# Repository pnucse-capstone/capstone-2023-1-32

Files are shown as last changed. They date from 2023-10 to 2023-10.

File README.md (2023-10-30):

# **WI-SUN FAN 네트워크를 활용한 스마트 공유 주차장**

## 1. 프로젝트 소개
자동차는 대부분의 시간을 주차장에서 보내고, 운전자는 주행 시간의 30% 이상을 주차 공간을 찾는데 쓴다는 연구 결과가 있습니다. 하지만, 기존의 여러 공유 주차장 서비스들이 있었음에도 불구하고, '부정 주차 문제'로 인한 한계점이 명확했습니다. 

저희는 '부정 주차 문제'를 해결하고자 차단기가 부착된 공유 주차장 모듈을 제작하였습니다. 이를 활용해 IoT 기반의 공유 주차장 솔루션을 제시하고 주차 비효율 문제를 해결하는데 도움을 주고자 합니다.

## 2. 팀 소개
- 지도 교수님: 정상화 교수님
- 지도 조교님: 이희준 조교님

|이름|정우영|이창주|홍유준|
|-|-|-|-|
|github| [](https://github.com/wyj3569) | [](https://github.com/busbtvi) | [](https://github.com/Kick-snare) |
|학번|201824580|201824565|201824615|
|email|wyjung0731@gmail.com|busbtvi@gmail.com| hyjhyj0901@naver.com |
|역할|Wi-SUN 모듈 개발|서버 & 케이싱|안드로이드 앱 개발|

## 3. 구성도
- 전체적인 서비스의 구조도

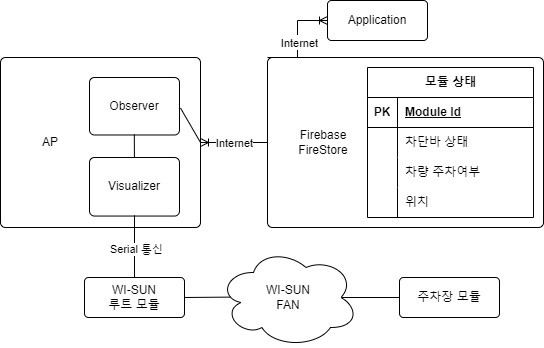
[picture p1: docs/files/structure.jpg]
서비스 전체 구조도
| 서비스 전체 구조도 |  |
| --- | :--- |
| **어플리케이션 서버** | 앱에서 활용할 데이터를 저장, Firebase의 FireStore를 활용 | 
| **AP(AccessPoint)** | 각 wi-sun 네트워크가 인터넷에 접속하기 위한 gateway |
| **WI-SUN Root Module** | AP에 연결되어 wi-sun fan 네트워크와 인터넷을 연결하는 역활 | 
| **주차장 모듈** | 차단기와 wi-sun 모듈을 포함하여, 주차장 바닥에 간단히 설치할 수 있는 모듈 |
| **애플리케이션** | 서버와 통신하며 사용자에게 UI 인터페이스를 제공 |

## 4. 소개 및 시연 영상

<!--| [<img width="500" src="https://github.com/pnucse-capstone/capstone-2023-1-32/assets/46425142/d3f03df4-c666-478d-8ad8-54723ae4332b"/>](https://youtu.be/7jfjwZkByfk?si=sUhvpEVTzl3uZno2) |
| --- |-->

정상주차장 팀 발표영상 (https://youtu.be/7jfjwZkByfk?si=sUhvpEVTzl3uZno2)

## 5. 사용법
> 이 프로젝트에 사용된 Wi-SUN 모듈의 경우, 기술적 권리로 인해 배포 및 공개가 금지되어 있습니다.
> 따라서, 해당 모듈과 관련된 source code 및 사용법은 이 repository 및 README에 포함하지 않았습니다.

### 5.1 주차장 모듈
> 주차장 모듈은 주차공간 소유자가 자신의 주차장에 간편하게 설치하여, 부정주차 차량을 차단할 수 있는것을 목표로 개발되었습니다.

#### 완성된 모듈

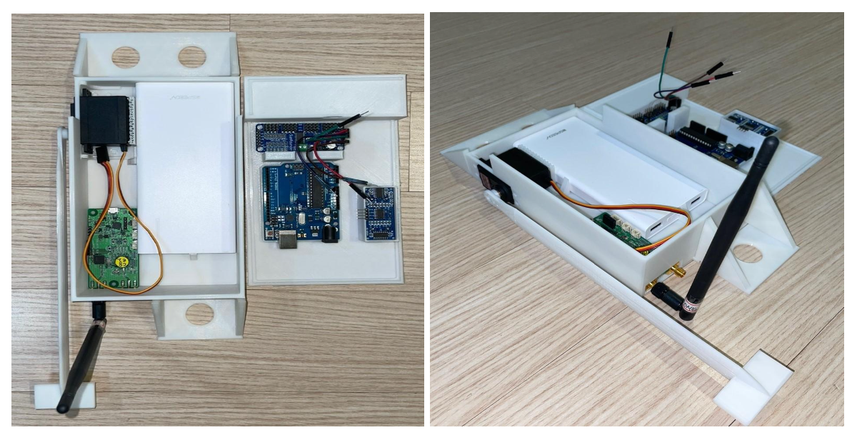
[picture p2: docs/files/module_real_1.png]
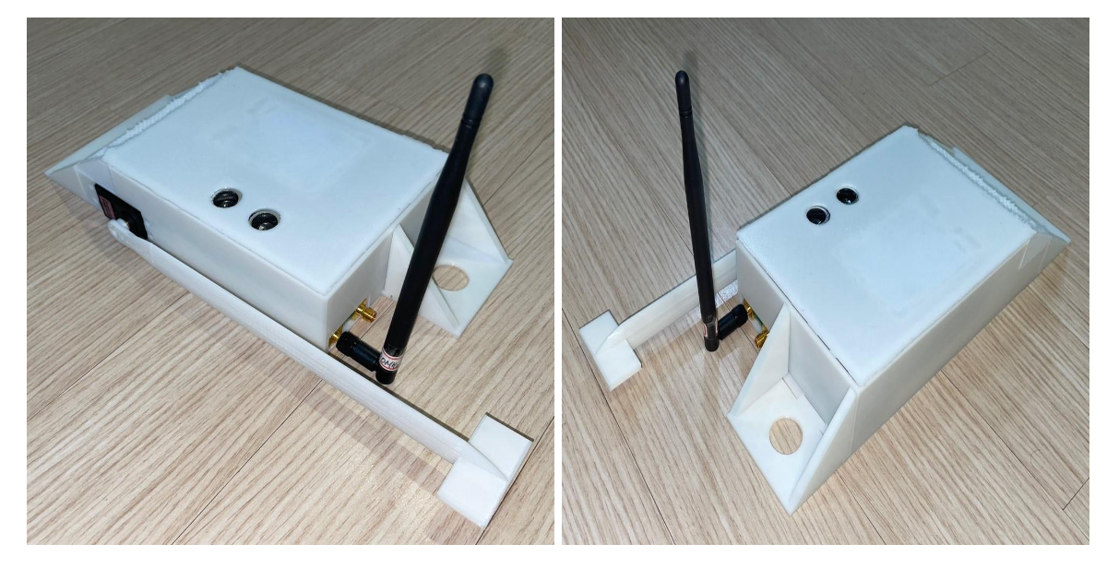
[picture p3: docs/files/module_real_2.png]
|  |  |
| --- | --- |

- 위의 주차장 모듈은 주차면에 차량이 주차되어 있는지 여부를 실시간으로 파악합니다.
- 주차장 모듈에 부정 주차를 방지할 수 있는 차단바 기능을 구현했습니다.
- 차단바의 움직임은 사용자가 애플리케이션을 통해서 조작합니다.
- 우리 공유 주차장 시스템은 Wi-SUN FAN 네트워크를 이용하여 통신합니다. 

Wi-SUN FAN 네트워크를 이용한 통신을 간략히 요약하면 다음과 같습니다.

- Wi-SUN FAN 네트워크의 모든 패킷은 루트 노드를 경유한다.
- 루트 노드를 관찰하는 옵저버를 둔다.
- 옵저버는 Wi-SUN 모듈과 서버 사이의 패킷을 중간에서 연결하는 역할을 수행한다.

### 5.2 Observer
> observer는 AP에서 실행되어, firebase와 wi-sun 모듈간의 양방향 통신을 책임지는 python 코드입니다.

<details>
<summary>**How to run**</summary>
    
#### How to run

1. python 3.* version
2. firebase 프로젝트에서 firebaseCredential.json을 다운받아 observer.py와 동일한 경로에 배치한다. 
    - 프로젝트 설정 -> 서비스 계정 -> 새 비공개키 생성
3. wireshark를 활용해 wi-sun모듈이 사용하고 있는 인터페이스 및 포트를 확인
    - port: observer.py 16 line 수정
    ```python
    port = ????
    ```
    - interface: observer.py 88 line 'iface' 값 수정
    ```python
    sniff(iface="????", prn = handlePacket, count = 0)
    ```
4. run observer.py

</details>

<details>
<summary>**코드 설명**</summary>

#### 코드 설명
- 서버를 firebase로 사용하고 있기 때문에, firebase 까지 업데이트를 하면 어플리케이션에서 자동으로 반영

1. 모듈 -> 어플리케이션
    1. 주차장 모듈에 설치된 wi-sun 모듈이 root 로 데이터를 전송
    2. root 모듈은 AP에 있는 visualizer에게 전달
    3. 2번의 과정을 python의 scapy를 활용해 캡처
        ```python
        from scapy.all import *
        sniff(iface="wisun", prn = handlePacket, count = 0)
        ```
    4. 패킷을 분석해 필요한 데이터 추출
        ```python
        def handlePacket(rowPacket)
        ```
    5. firestore에 업데이트
        ```python
        def updateDocument(mac, isOcupied): nodeRef.document(mac).update({"isOcupied": isOcupied})
        ```
2. 어플리케이션 -> 모듈
    1. observer에서 firestore에 대한 EventListener 등록
        ```python
        # 변화를 감지할 collection(일종의 table)
        nodeRef = firestore.client().collection("module")
        
        # 현재 observer와 관련된 문서만 탐지
        col_query = nodeRef.where(filter=FieldFilter("observerId", "==", observerId))
        query_watch = col_query.on_snapshot(documnetEventListener)
        ```
    2. 문서의 flag 필드값을 확인
        ```python
        for change in changes:
            if change.type.name == "MODIFIED":
                msg = 0 if change.document.get("isBlocked") else 1
        ```
    3. 데이터(제어신호)를 socket을 활용해, interface로 전달
        ```python
        def sendToNode(dst, msg):
        print("sendToNode")
        sendSocket.connect((dst, port))
        sendSocket.send(msg.to_bytes(1, 'big'))
        ```
</details>

### 5.3 Android

스크린샷 2023-10-27 오후 11 45 56

사용자의 모바일 어플리케이션과 주차장 모듈 간의 통신을 위해 Firebase의 FireStore 서비스를 사용한다. 모듈과 모바일 앱과 같은 다른 클라이언트와 통신하기 위해서 많은 부분이 계층화되어 있기 때문에 모바일 애플리케이션은 주차장 관련 정보를 오직 firestore를 인터페이스로 주고 받는다. 

#### 회원가입 및 로그인

| 로그인 | SNS연동 | 회원가입 |
| --- | --- | --- |
|  |  |  |

주차장을 대여하거나, 제공하는 사용자 모두 회원가입을 통해 로그인이 필요하다. 간편한 로그인을 지원하기 위해 카카오의 SNS 로그인을 지원하도록 연동하였다. 따라서 사용자는 별다른 입력 없이 바로 로그인 할 수 있다.

#### 지도 기반 주차장 탐색

|  |  |  |  |
| --- | --- | --- | --- |

기본적으로 앱을 실행하였을 때 사용자는 지도를 통해 주차장의 여러 정보를 얻을 수 있다. 자신의 위치를 비롯한 주차장들의 위치와 이름이 지도상의 마커로 표시 된다. 

하단 네비게이션바 위 쪽의 “-” 모양의 핸들을 드래그하여 올리게 되면 주차장들의 간략한 정보가 담긴 카드 리스트가 노출된다. 이는 지도 상에 노출되는 주차장들의 더욱 자세한 정보를 알 수 있으며, 카드 우측 상단의 별 모양을 통해 즐겨찾기를 등록 또는 해제 가능하다. 이는 서버에 즉시 반영되며, 등록된 주차장은 “즐겨찾기” 탭에서 모아 보기 가능하다.

주차장 마커를 클릭하거나, 아래 리스트에서 카드를 클릭하게 되면 왼쪽 화면과 같이 지도의 시점이 고정되며 현재 위치로부터 주차장 위치의 경로를 애니메이션으로 보여준다. 동시에 지도 상에 떠있는 주차장 카드가 노출되며, 해당 카드를 클릭하면 주차장의 상세 정보와 함께 결제를 할 수 있는 화면으로 이동하게 된다.

### 사용 시간에 따른 필터링

| 주차장 사용 시간 | 날짜 선택 | 시간 선택 |
| --- | --- | --- |
|  |  |  |

사용자는 자신이 주차를 원하는 시작 시간과 종료 시간을 설정하여 이 조건에 맞게 사용할 수 있는 주차장을 탐색하고, 해당하는 가격을 결제하여 사용할 수 있다. 편리한 사용을 위해 아래 “+” 또는 “-”가 붙은 버튼을 클릭하여 간편하게 시간을 조정할 수 있다. 하단 아래의 큰 버튼을 눌러 적용한다.

#### 주차장 모듈 등록

| 주차장 관리 | 권한 획득 | QR코드 스캔 | 주차장 정보 입력 |
| --- | --- | --- | --- |
|  |  |  |  |

주차장을 제공자로서 사용하기 위해서는 모듈을 동작시켜 네트워크상에 연결되고 나서, 주차장에 대한 세부 정보와 제공자가 누구인지 등 등록하는 과정이 필요하다. 추후 모듈을 제공할 때 케이스에 QR스티커 등을 부착하여 모바일 애플리케이션에서 카메라로 인식하여 간단하게 구현할 수 있도록한다. 
 인식이 된 모듈은 주차장의 이름, 위치, 가격등을 설정하여 서버에 저장되고, 최종적으로 사용자에게 노출되게 된다. 

### 5.4 Casing(H/W)
> 이번 과제에서 사용된 모든 모델링 파일은 /docs/files/*.stl 파일에 있습니다.

케이싱은 주차장 모듈에 필요한 센서와 보드들이 모두 안전하게 보관 및 동작할 수 있도록 모델링을 진행했습니다. 

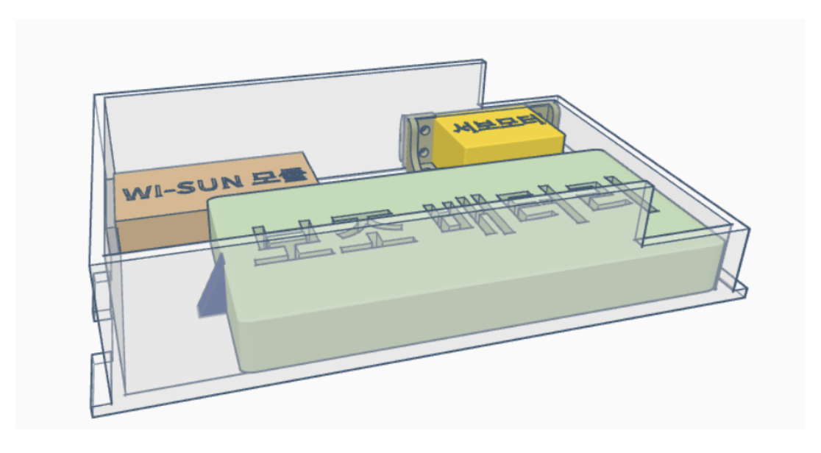
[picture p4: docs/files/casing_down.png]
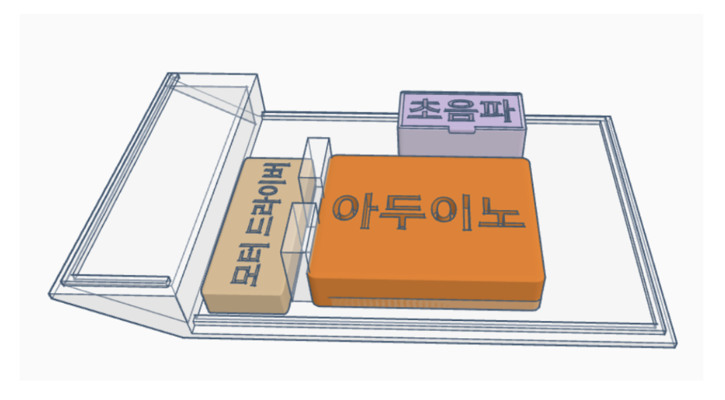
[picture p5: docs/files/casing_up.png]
|  |  | 
| --- | --- |

- 차단바를 움직이는데 필요한 서보모터의 구동축은 바깥에서 보이도록 하였고, WI-SUN 모듈의 안테나도 외부에서 장착할 수 있도록 제작했습니다.
- 초음파 센서는 위쪽의 차량의 주차여부를 판단해야 되기 때문에 케이싱의 뚜껑부분에 장착될 수 있도록 제작했습니다.

#### 전체 케이싱

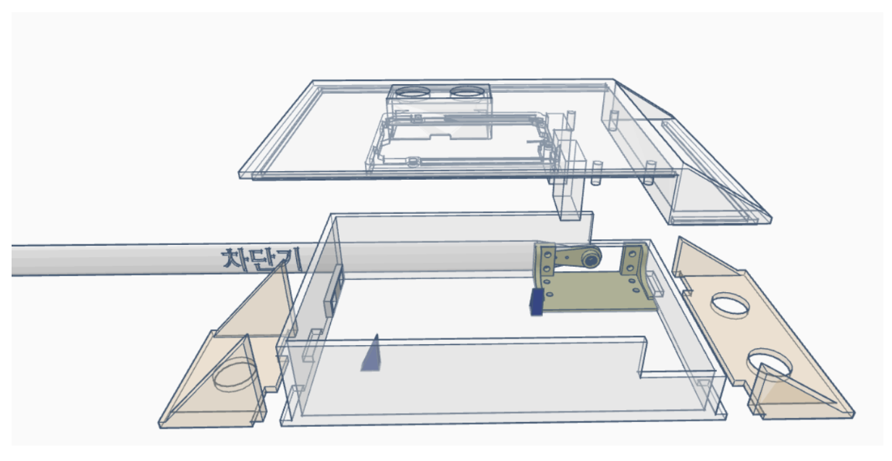
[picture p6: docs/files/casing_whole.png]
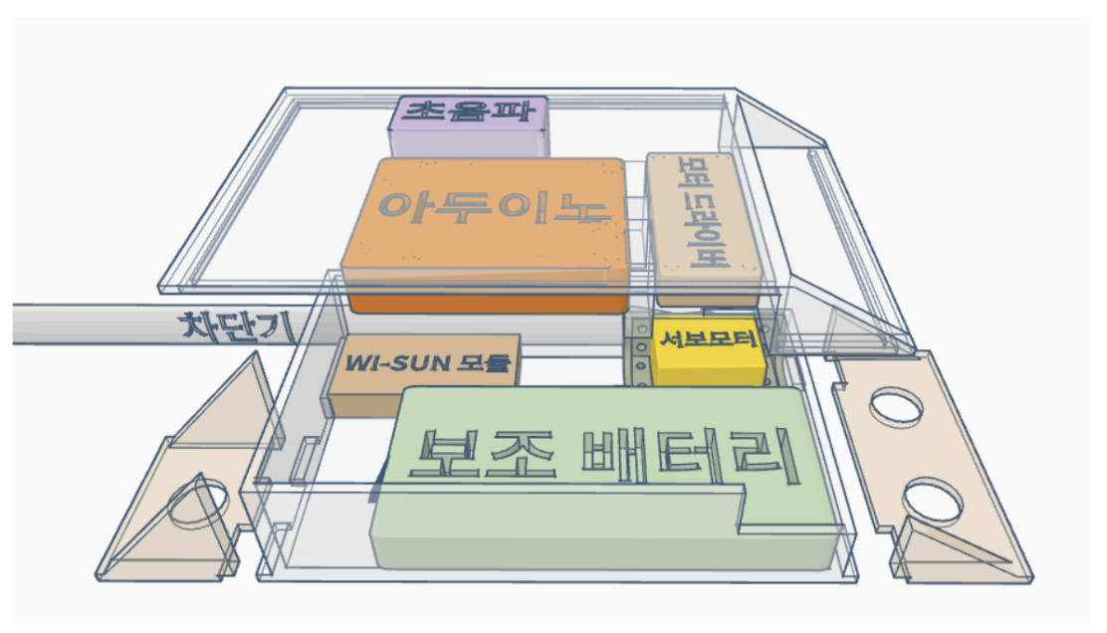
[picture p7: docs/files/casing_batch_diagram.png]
|  |  | 
| --- | --- |

- 모듈이 주차장 바닥에 안정적으로 고정될 수 있도록 케이싱의 좌우에 지지부를 따로 빼내어 바닥에 볼트를 박을 수 있도록 설계
- 지지부가 케이스에 정확히 연결 될 수 있도록 케이싱 및 지지부에 가이드 추가

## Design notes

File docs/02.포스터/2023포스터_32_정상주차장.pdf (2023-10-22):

# Wi-SUN FAN 네트워크를 활용한

# 33 스마트 공유 주차장

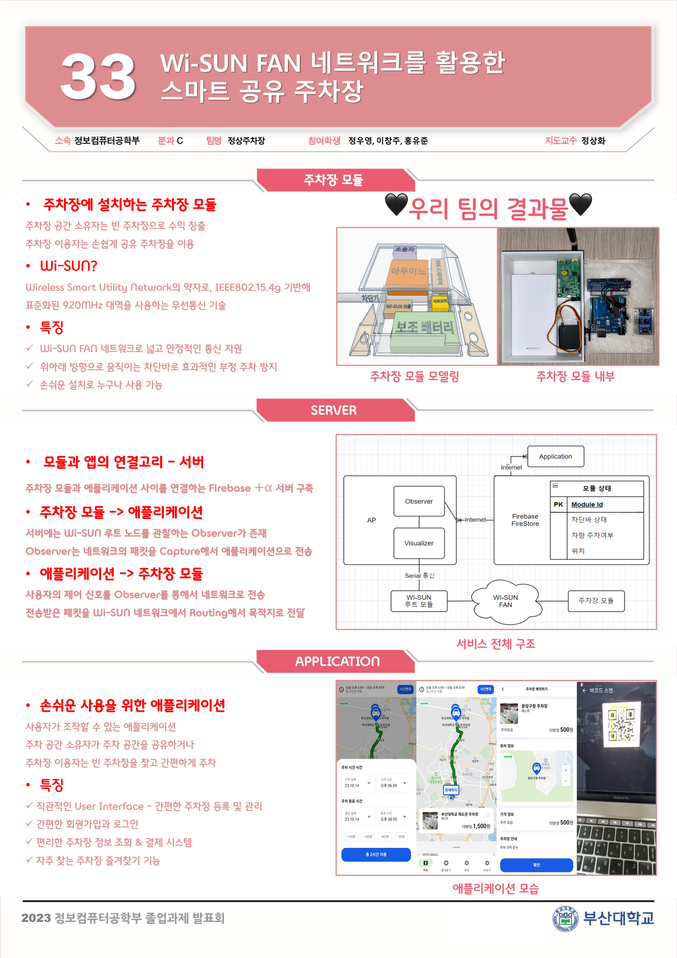
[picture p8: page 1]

정상주차장 | 정우영, 이창주, 홍유준 | 정상화

### 주차장 모듈

### SERVER

### APPLICATION

2023

주차장 모듈 모델링 | 주차장 모듈 내부

## - 주차장에 설치하는 주차장 모듈

주차장 공간 소유자는 빈 주차장으로 수익 창출
주차장 이용자는 손쉽게 공유 주차장을 이용

## - Wi-SUN?

Wireless Smart Utility Network의 약자로, IEEE802.15.4g 기반해 표준화된 920MHz 대역을 사용하는 무선통신 기술
- 특징

ü Wi-SUN FAN 네트워크로 넓고 안정적인 통신 지원
ü 위아래 방향으로 움직이는 차단바로 효과적인 부정 주차 방지 ü 손쉬운 설치로 누구나 사용 가능

# 🖤우리 팀의 결과물🖤

## - 모듈과 앱의 연결고리 서버

주차장 모듈과 애플리케이션 사이를 연결하는 Firebase +α 서버 구축

## - 주차장 모듈 -> 애플리케이션

서버에는 Wi-SUN 루트 노드를 관찰하는 Observer가 존재 Observer는 네트워크의 패킷을 Capture해서 애플리케이션으로 전송

## - 애플리케이션 -> 주차장 모듈

사용자의 제어 신호를 Observer를 통해서 네트워크로 전송
전송받은 패킷을 Wi-SUN 네트워크에서 Routing해서 목적지로 전달

## - 손쉬운 사용을 위한 애플리케이션

사용자가 조작할 수 있는 애플리케이션
주차 공간 소유자가 주차 공간을 공유하거나
주차장 이용자는 빈 주차장을 찾고 간편하게 주차
- 특징

ü 직관적인 User Interface 간편한 주차장 등록 및 관리 ü 간편한 회원가입과 로그인
ü 편리한 주차장 정보 조회 & 결제 시스템
ü 자주 찾는 주차장 즐겨찾기 기능

### 서비스 전체 구조

### 애플리케이션 모습

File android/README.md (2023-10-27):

# NormalizeParkingLot-android
Normalize the Parking Lot (NPL) android repository

### How To Run
```
1. add local.properties
2. sync gradle
3. build & run
```
request @kick-snare `local.properties` that contains api key

### app architecture

```mermaid
flowchart TD
    A[app] --> B(data)
    A[app] --> G(presentation)
    G --> B
    G --> C{ui}
    C --> D[map]
    C --> E[favorite]
    C --> H[provider]
    C --> F[setting]
    B --> repository
    repository --> interface
    repository --> impl
    B --> di
    B --> remote
    remote --> service
    remote --> dto
    B --> local
    local --> dao
    local --> entity
```
with MVVM

### tech stacks
- Jetpack Compose
- Kotlin Coroutine
- Dagger Hilt
- FireStore
- Retrofit
- Coil
- etc...

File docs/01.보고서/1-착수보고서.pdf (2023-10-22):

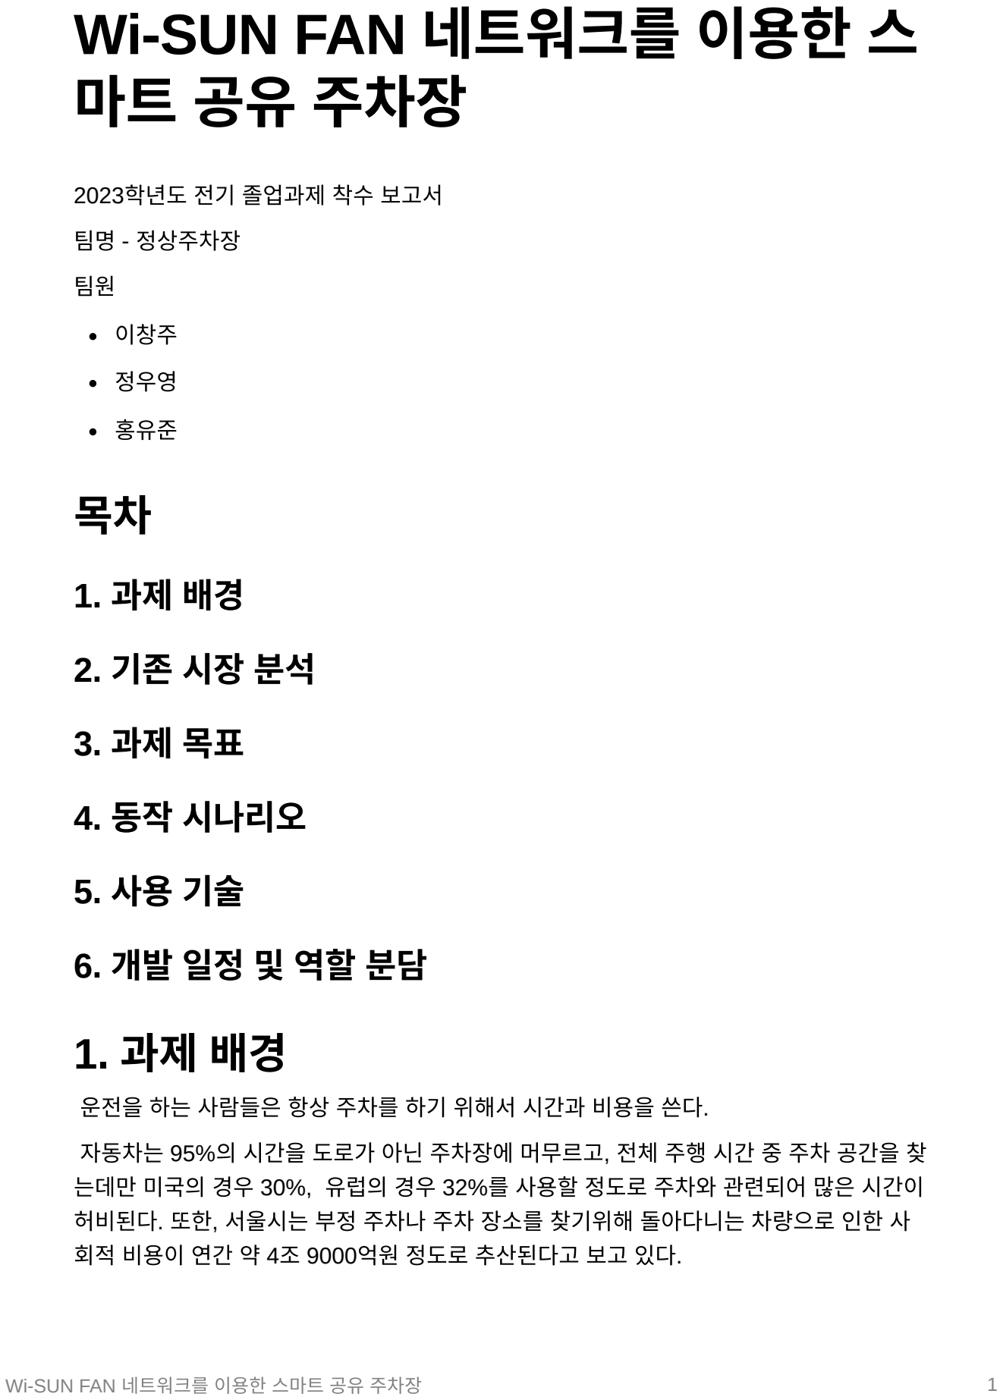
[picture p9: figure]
Wi-SUN FAN 네트워크를 이용한 스마트 공유 주차장; Wi-SUN FAN 네트워크를 이용한 스 마트 공유 주차장; 2023학년도 전기 졸업과제 착수 보고서; 팀명 - 정상주차장; 이창주; 정우영; 홍유준; 4. 동작 시나리오; 운전을 하는 사람들은 항상 주차를 하기 위해서 시간과 비용을 쓴다.; 회적 비용이 연간 약 4조 9000억원 정도로 추산된다고 보고 있다.

자동차는 95%의 시간을 도로가 아닌 주차장에 머무르고, 전체 주행 시간 중 주차 공간을 찾 는데만 미국의 경우 30%, 유럽의 경우 32%를 사용할 정도로 주차와 관련되어 많은 시간이 허비된다. 또한, 서울시는 부정 주차나 주차 장소를 찾기위해 돌아다니는 차량으로 인한 사

그러나 이러한 문제가 ‘주차 공간 부족’ 때문만은 아니다. 실제 통계 자료에 따르면, 서울시 의 경우 평균 주차공간 확보율이 2022년 기준 141%, 종로구의 경우는 무려 185.5%로 등록 된 차량보다 주차 공간이 거의 2배에 가까운 상황이다.

충분한 주차공간이 있음에도 불구하고, 주차와 관련된 비효율이 높은 이유는 주차공간에 대 한 수요와 공급이 불균형하기 때문이라는 연구 결과가 존재한다. 주차 공간의 전체 공급은 충분하지만, 주차 공간의 수요는 특정 시간대에만 몰려있기 때문에 비효율이 발생한다는 것 이다. 이러한 문제를 해결하기 위한 방안으로 ‘공유 주차장’ 개념이 고안되었고, 현재 시중에 이러한 서비스가 존재하고 있다.

하지만 부정 주차 문제를 쉽게 해결할 수 없기 때문에 여전히 여러 문제가 존재한다. 이러한 문제를 해결하기 위해서 우리 팀은 여유 부지를 공유주차장으로 쉽게 운영하면서도 부정 주 차 문제를 해결할 수 있는 `IoT(Internet of Things) 기반 공유 주차장 서비스’를 제안하고 자 한다.

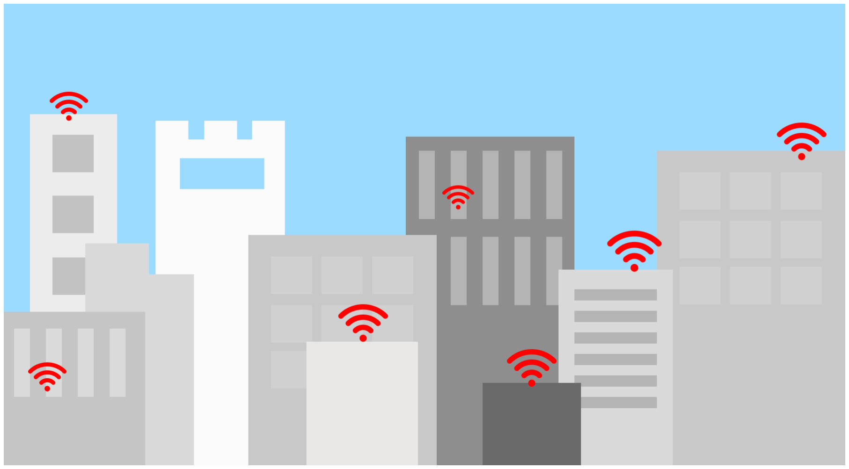
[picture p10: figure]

해당 서비스를 개발하기 위해서 주차면에 간단하게 설치할 수 있는 Iot 모듈과, 관련 서비스 를 쉽게 제공하고자 소프트웨어를 개발하고자 한다. 모듈간의 통신을 위해서 IPv6 주소체계 를 기반으로 넓은 범위를 효율적으로 커버할 수 있는 Wi-SUN FAN (Wireless Smart Utility Network-Field Area Network)을 사용한다. 추가적으로 네트워크의 성능 향상과 관련된 연 구를 수행해서 더욱 빠르고 효율적인 네트워크 시스템을 구축해보고자 한다. 사용자들에게 해당 서비스를 제공하기 위한 모바일 애플리케이션을 개발한다.

# 2. 기존 시장 분석

## 2.1 모두의 주차장

‘모두의 주차장’은 대표적인 주차장 공유 사업, 주차장 제휴 사업, 주차장 정보 사업 등을 모 바일 애플리케이션 형태로 사용자들에게 제공하는 플랫폼이다.

특히, 주차 공유 서비스는 주차공간 소유자와 운전자가 주차장을 공유할 수 있도록 연결해 주는 서비스로 거주자 우선 주차면과 사유지 주차공간을 공유하도록 하는 서비스이다. 주차 공간 소유자는 해당 서비스를 통해 비워두는 시간을 활용해서 수익을 얻고, 운전자는 공유 주차장을 활용해 저렴한 가격으로 단속 걱정 없이 편리하게 주차할 수 있다.

모두의 주차장은 현재도 지속적으로 서비스를 제공하고 있다. 하지만, 공유 주차장의 부정 주차 방지 수단으로 경고 문구 부착, 부정주차 단속 및 차주에게 직접 말하기와 같은 방법에 의존하고 있다. 그래서 실제 사용자들이 막상 공유 주차 공간에 갔을 때 부정주차 차량이 이 미 자리하고 있는 경우가 있다는 점이 단점으로 지적되고 있다. 따라서, 부정주차를 효과적 으로 예방할 수 있는 방안을 마련할 필요가 있어 보인다.

2.2 파킹플렉스 (https://medium.com/@TaerimPark_CEO/%ED%8C%8C%ED%82%B9%ED%94%8C%EB%A0%89%EC%8A%A4-%ED%9A%8C%EA%B3%A0%EB%A1%9D-6a1653b7a5be)

‘파킹플렉스’는 2017년 서비스를 종료한 IoT 기반의 주차공간 공유 서비스이다. 파킹플렉스 는 주인의 동의를 받은 주차 공간에 차량을 감지할 수 있는 IoT 센서를 부착해서 주차 공간의 상태 정보를 애플리케이션을 통해 운전자에게 실시간으로 전달하는 서비스를 개발했었다. 그러면 운전자는 주차 공간을 찾아가서 애플리케이션을 통해 주차비를 지불하고 주차 공간 을 사용할 수 있었다.

하지만, 주차 공간 주인에게 돌아가는 수익이 낮은 점, 불법 주차 예방 효과 미미, 불편한 애 플리케이션 사용자 경험, 당시 사람들에게 익숙하지 않은 IT 기반 서비스 등과 같은 문제로 서비스를 종료하게 되었다.

특히, 파킹플렉스는 부정주차 방지 솔루션으로 (1)공유 설정된 주차 공간에서 주차비를 결 제하지 않고 10분 이상 지난 경우, (2)공유 미설정된 주차 공간에서 10분 이상 차량이 주차 된 경우 해당 구청이나 공간 소유자에게 알림을 보내는 방법을 사용했다. 이러한 소극적인 대응 방법 때문에 부정 주차 예방 효과가 미미하여 공간 소유자로 하여금 서비스를 사용하게 할 동기를 주지 못했던 것으로 판단된다.

출처-모두의주차장 (https://www.moduparking.com/)

이러한 사례를 미루어 보아, 더욱 적극적으로 부정주차를 예방할 수 있는 방법을 찾을 필요 가 있어 보인다. 또한, 더욱 사용자 친화적인 경험을 제공한다면 당시보다 더욱 많은 사람들 이 IT 기반 서비스에 익숙해진 지금 성공적인 서비스가 될 수 있을 것이라 생각한다.

# 3. 과제 목표

## 3.1 주차장 모듈 개발

주차 공간 소유자가 자신의 주차 공간을 운전자에게 공유하고자 할 때, 관련 기능을 제공할 수 있는 주차장 모듈을 개발한다. 아래에 제시된 기능들을 모두 하나의 모듈로 제작해서 간 편하게 설치할 수 있는 형태를 제안한다.

주차장 모듈에 필요한 기능으로 다음이 있다.

(1) 주차 가능 여부 파악 기능

주차면에 설치된 모듈에서 초음파 센서를 활용하면 주차 여부를 판단할 수 있다. 초음파 센 서로 파악한 주차 가능 여부를 서버에 보내주면, 운전자는 모바일 애플리케이션을 통해서 근 처에 주차 가능한 공유 주차장의 존재를 확인할 수 있다.

(2) 부정 주차 방지를 위한 차단 기능

주차장 모듈에는 부정 주차 방지를 위한 차단 기능이 존재한다. 일반적으로 주차장은 아래 의 그림과 같이 2가지 유형의 배열로 구성되어 있다. 보통 위의 유형은 공영 주차장과 같은 곳에서 볼 수 있고, 아래의 유형은 주택가와 같은 곳에서 볼 수 있는 주차장 배열이다.

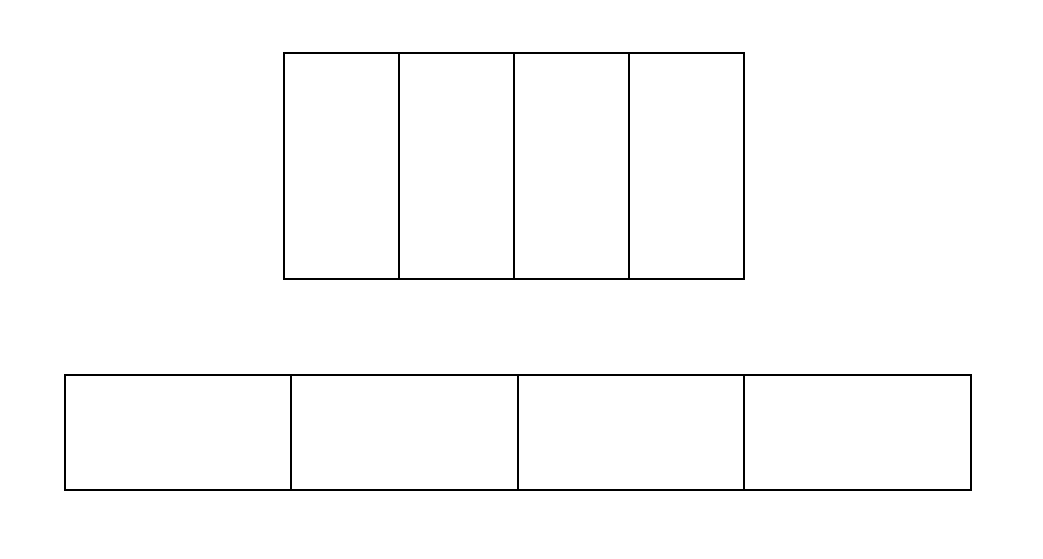
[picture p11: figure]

만약, 아래와 같이 흔히 볼 수 있는 차단기를 설치한다면 2가지 길이의 차단기를 제작해야 하고, 또한 주차면마다 이와 같은 차단기를 설치한다면 진입 공간을 방해하고 비용도 많이 드는 문제점이 있다.

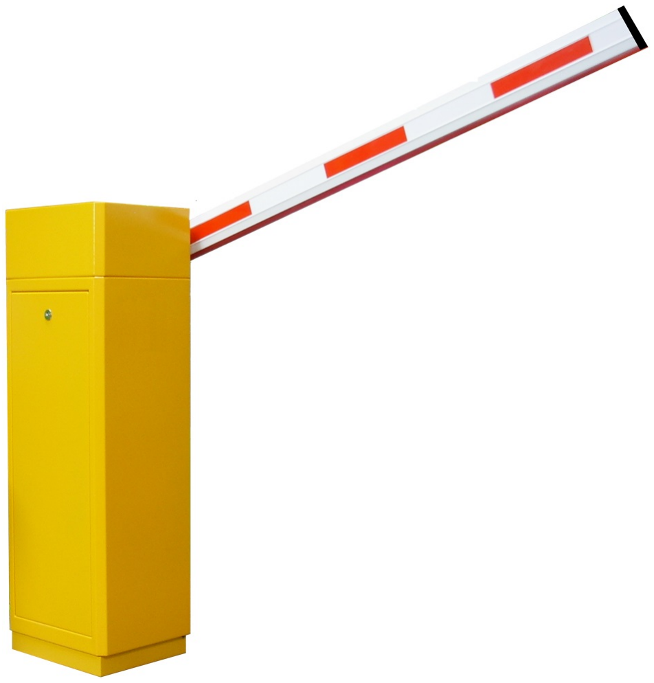
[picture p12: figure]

이러한 문제점을 해결하기 위해서 발상을 전환하여 아래와 같이 주차면 바닥에서 서고 접을 수 있는 형태의 차단기를 제작하고자 한다. 이와 같은 차단기를 주차면의 중앙에 하나씩 설 치한다면 동일한 길이의 차단기를 하나만 제작해도 되고, 부정 주차 차량의 진입을 제한할 수 있으며, 주차 가능 여부를 확실하게 판단할 수 있을 것이다.

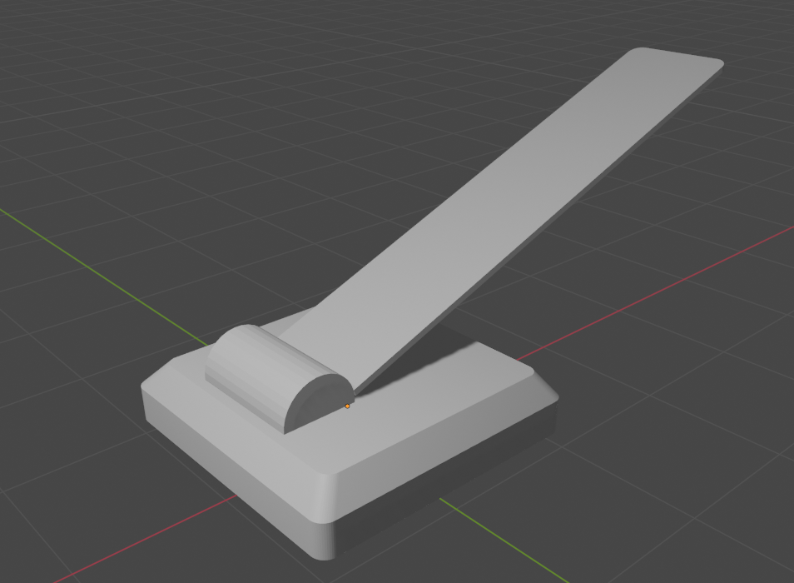
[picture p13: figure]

(3) Wi-SUN FAN을 통한 통신 기능

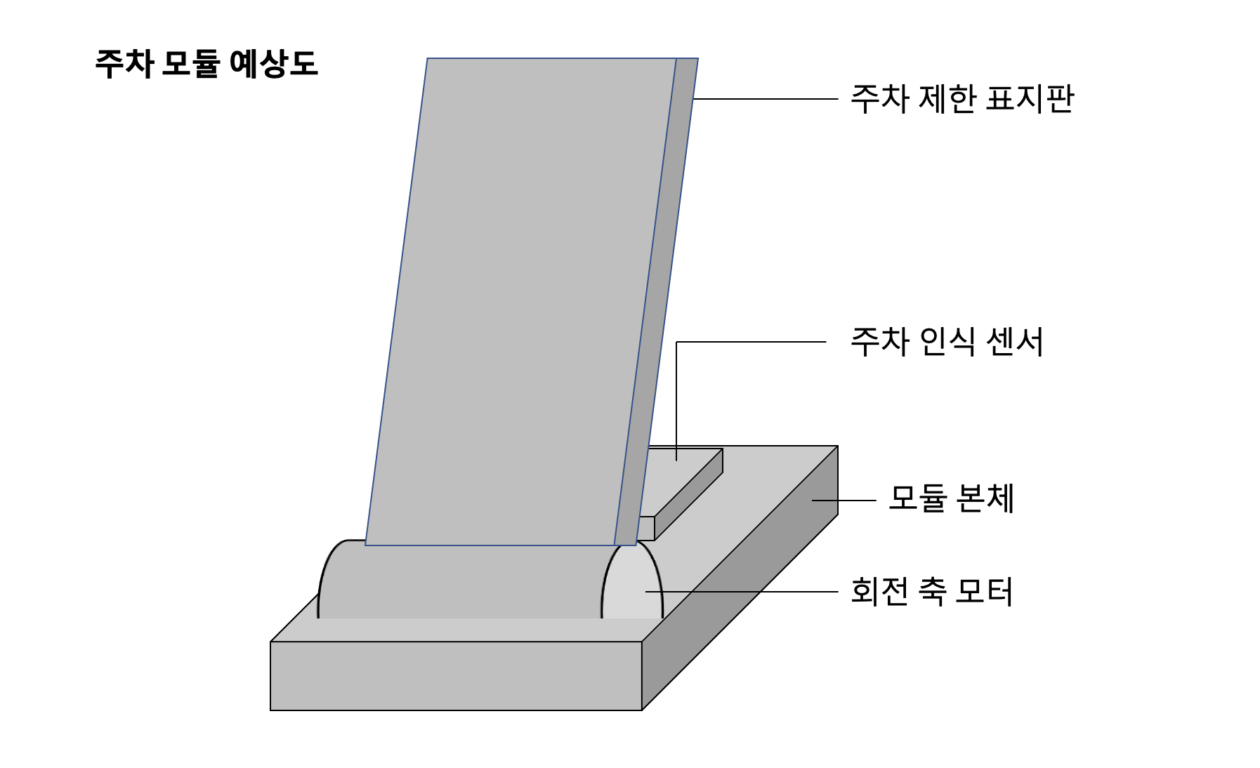
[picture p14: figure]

주차 모듈에 Wi-SUN FAN 모듈을 장착하여 상호간의 통신을 수행한다.

## 3.2 애플리케이션 개발

주차 공간 소유자와 운전자가 공유 주차 서비스를 사용할 수 있도록 애플리케이션을 개발한 다.

(1) 회원가입 및 로그인 기능
(2) 지도 서비스를 통한 주차 가능 공간 안내 기능
(3) 주차 공간 예약 기능
(4) 자주 사용하는 주차공간 예약기능

출처-건일하이텍 (http://kiht.net/product1/)

(5) 디지털 결제 기능과 결제 기록 제공 기능

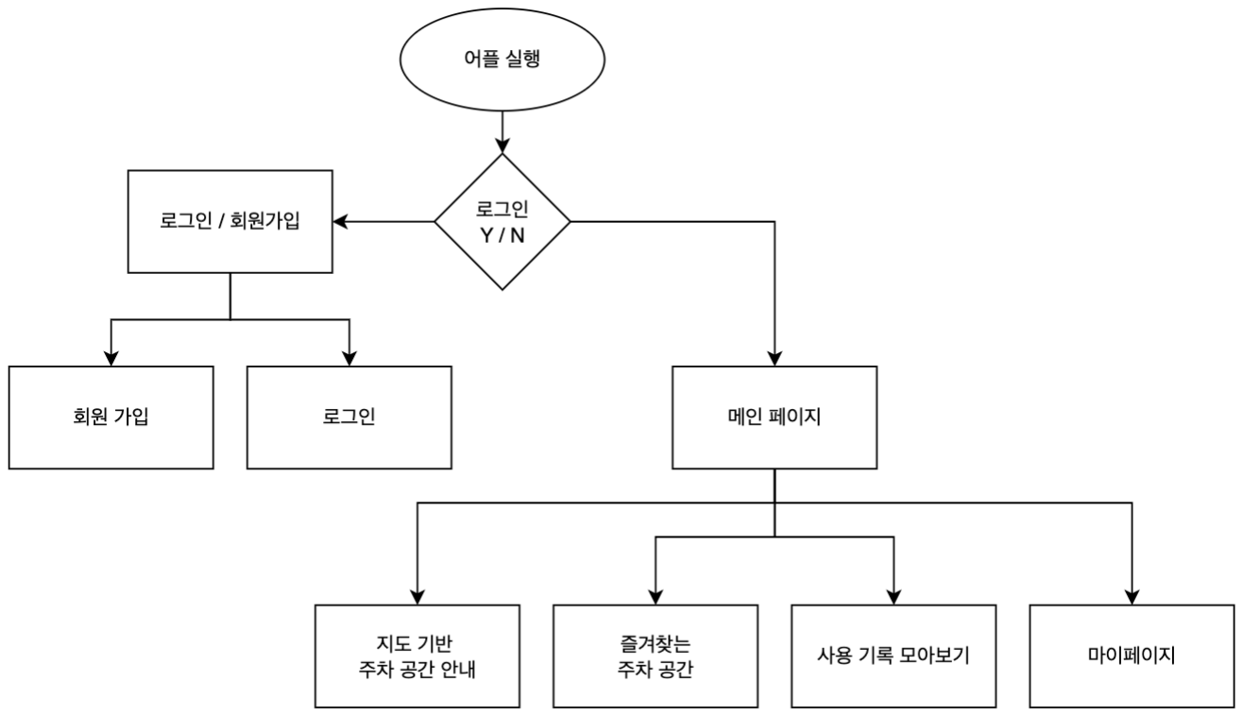
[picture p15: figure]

## 3.3 서버 개발

주차장 모듈과 모바일 클라이언트 애플리케이션 사이에서 정보를 관리하는 서버를 개발한 다.

(1) 주차장 모듈로부터 주차 가능 여부 송신 기능
(2) 사용자 애플리케이션에게 주차 가능 여부 수신 기능
(3) 사용자 관리 기능
(4) Wi-SUN FAN 기반의 통신 기능
(5) REST API를 통한 인터페이스 제공 기능

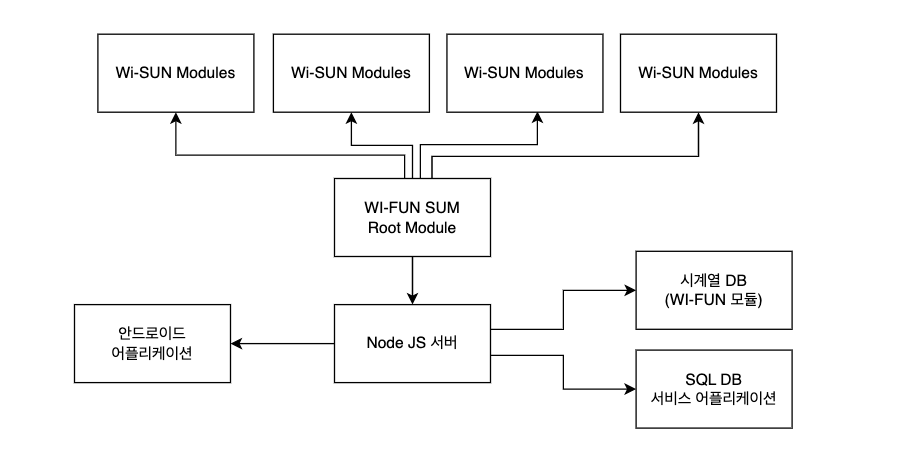
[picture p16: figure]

## 3.4 네트워크 성능 개선

Wi-SUN FAN 네트워크 자체의 성능 향상과 관련된 연구를 수행한다.

예상 가능한 연구 주제로는 다음이 있다.

(1) RPL(IPv6 Routing Protocol for Low-power Lossy Networks) 경로 설정 최적화 연구
(2) 공유 주차 서비스에 최적화된 데이터 포맷, 송수신 주기 탐색 연구

# 4. 동작 시나리오

### 4.1 주차 공간 소유자의 경우

주차 공간을 소유한 사람이 주차공간이 놀고 있는 시간에, 잠시 대여를 해 약간의 수익을 창 출 하고 싶을 때, 어플리케이션을 다운받아 공간 소유자로 등록을 하고, 모듈 구매한다. 그리 고 모듈을 원하는 위치의 주차 공간 바닥면에 설치하고 해당 위치를 어플리케이션으로 등록 한다.

등록한 주차공간에 사용될 때 마다 알림을 받아보는 등 실시간 상태와 수익률등을 확인할 수 있으며 원하지 않는 경우 주차지 공유를 중지할 수 있다.

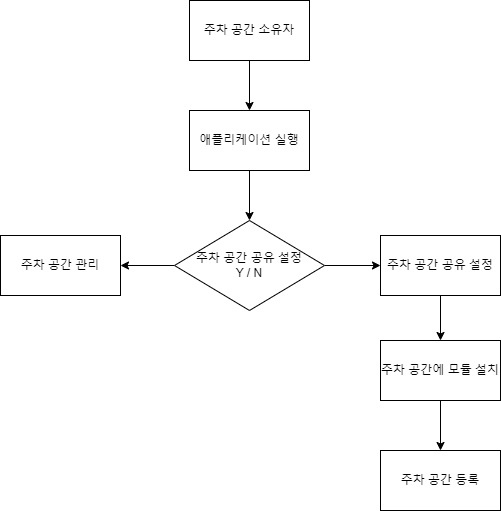
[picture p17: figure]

### 4.2 운전자의 경우

일반 사용자는 주차 공간이 필요한 경우, 어플리케이션 상의 지도에서 원하는 지역에 유휴 주차 공간을 찾아볼 수 있다. 적절한 주차지를 찾는다면 원하는 시간만큼 해당 공간에 대한 예약이 가능하다.

사용자가 예약한 주차장에 도착하면 어플리케이션 상에서 사용자의 위치를 인식하여 서버와 연결된 차량 차단장치가 해제되어 주차가 가능해진다. 사용자가 주차를 끝내고 장소를 이탈 하고 나면, 모듈에 탑대된 초음파 센서로 인식하여 자동으로 차량 차단장치를 가동해 주차공 간의 부정 이용을 제한한다.

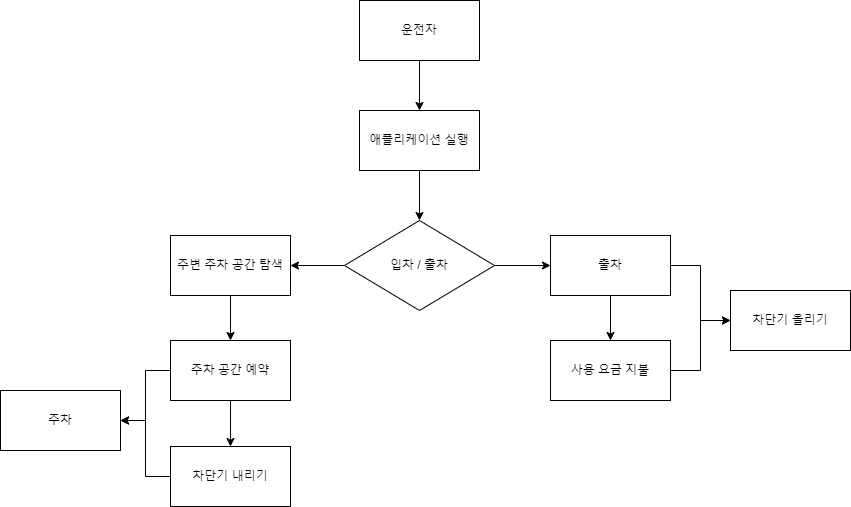
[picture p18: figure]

# 5. 사용 기술

## 5.1 WI-SUN FAN

Wi-SUN은 Wireless Smart Utility Network의 약자로, 920MHz 주파수를 사용하는 무선 통신 규격이다. Wi-SUN은 2.4GHz 및 5GHz대 주파수를 사용하는 Wi-Fi에 비해 통신 속도 는 느리지만, 통신 거리가 길고 장해물에도 강하기 때문에 통신이 용이하며, 저소비전력이라 는 장점이 있는 사물인터넷 전용 네트워크이다.

Wi-SUN은 최하층 프로토콜 베이스로 IEEE 802.15.4g를 사용하고, 그 상위층은 어플리케 이션에 따라 Profile이 정해져 있다. 이 중 FAN 응용은 사회 기반 시설, 고도 도로 교통 시스 템 등 스마트 시티, 스마트 그리드를 구축하는 다양한 어플리케이션을 상정한 Field Area Network용 프로파일이다.

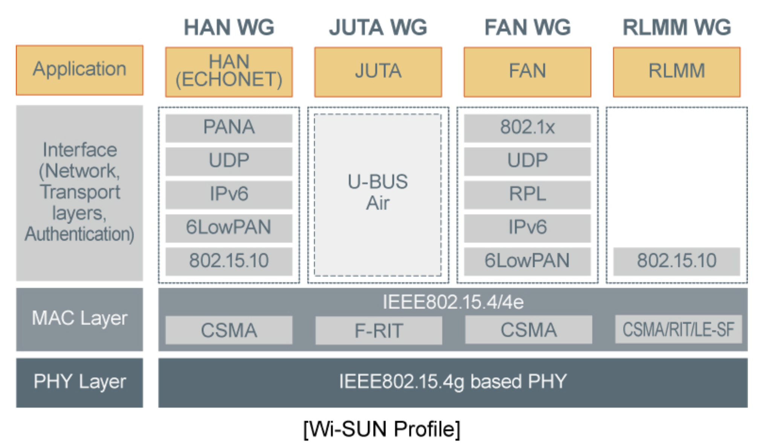
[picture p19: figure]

## 5.2 Android

리눅스 커널을 기반으로 구글에서 제작하고 있는 모바일용 운영체제이다. 커널은 C, C++로 작성되있고, UI 및 소프트웨어는 Java(또는 Kotlin)로 ART(Android RunTime)에서 동작한 다.

## 5.3 Node.js

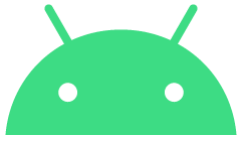
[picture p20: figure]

오픈소스 자바스크립트 엔진인 ‘V8’에 비동기 이벤트 처리 라이브러리인 ‘libuv’를 결합한 플랫폼으로, 자바스크립트 코드를 브라우저 외부에서 실행할 수 있게 해준다.

본 과제에서는 Node.js를 WI-SUN 모듈과 모바일 애플리케이션을 연결하는 서버로써 활용 할 예정이다.

출처-ROHM (https://www.rohm.co.kr/electronics-basics/wireless/wireless_what4)

출처-안드로이드 (https://www.android.com/intl/ko_kr/)

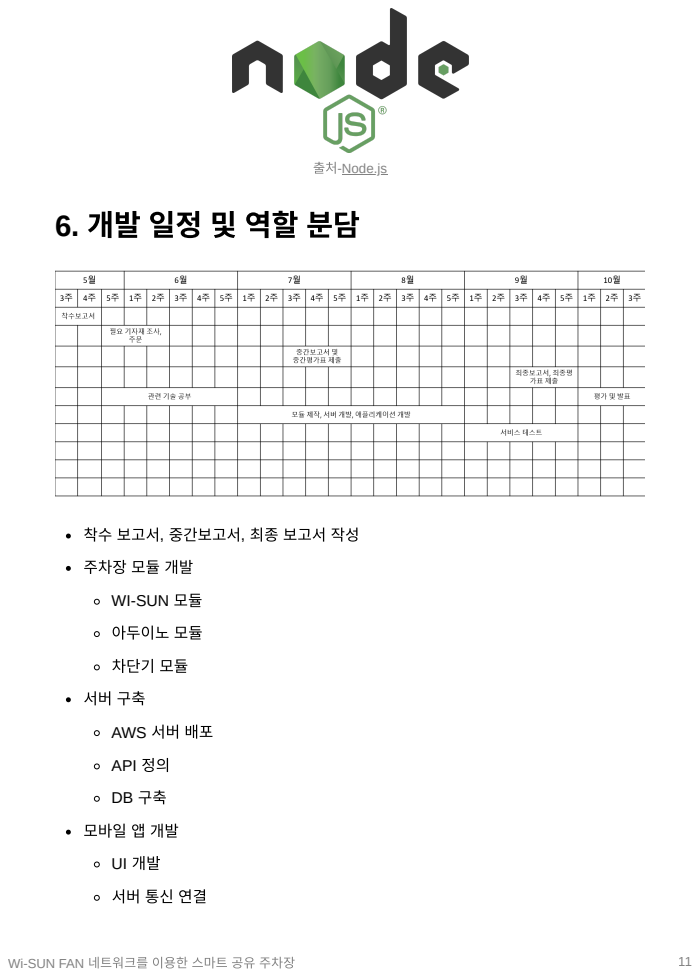
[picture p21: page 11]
아두이노 모듈; 차단기 모듈; 모바일 앱 개발

출처-Node.js (https://nodejs.org/ko)

착수 보고서, 중간보고서, 최종 보고서 작성

주차장 모듈 개발
WI-SUN 모듈

AWS 서버 배포
API 정의

로컬 DB 구축

| 역할
공통 | WI-SUN FAN 네트워크 망 연결 및 구축
정우영 | 모듈 제작, 네트워크 프로그래밍
이창주 | WI-SUN 루트 모듈과 서버 통신 연결, NodeJS서버 구축
홍유준 | 서비스 모바일 안드로이드 어플리케이션 구현

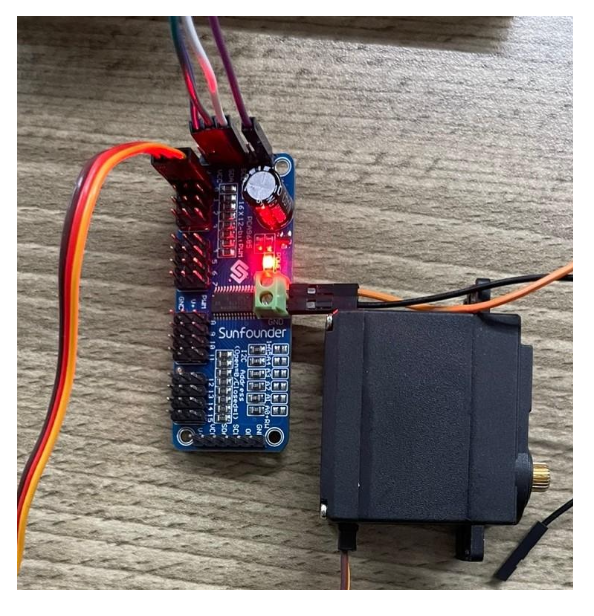
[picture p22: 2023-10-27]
docs/files/motor driver and servo motor.png

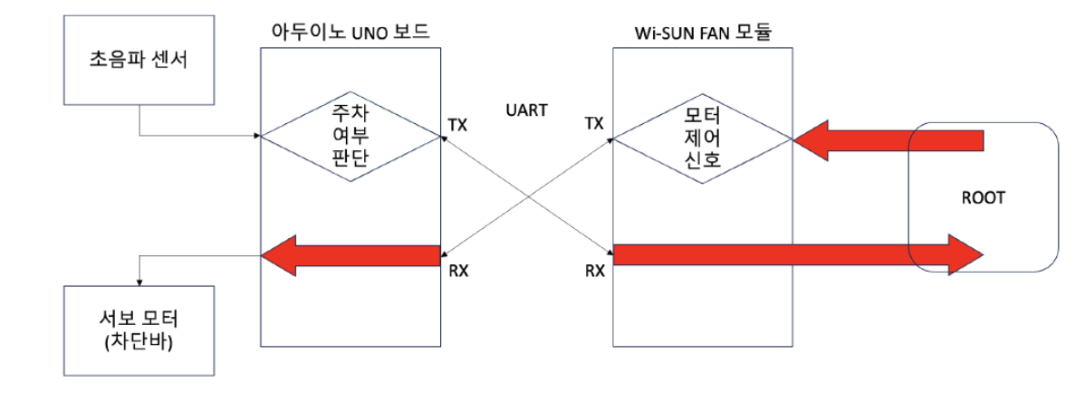
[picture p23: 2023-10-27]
docs/files/module structure.png

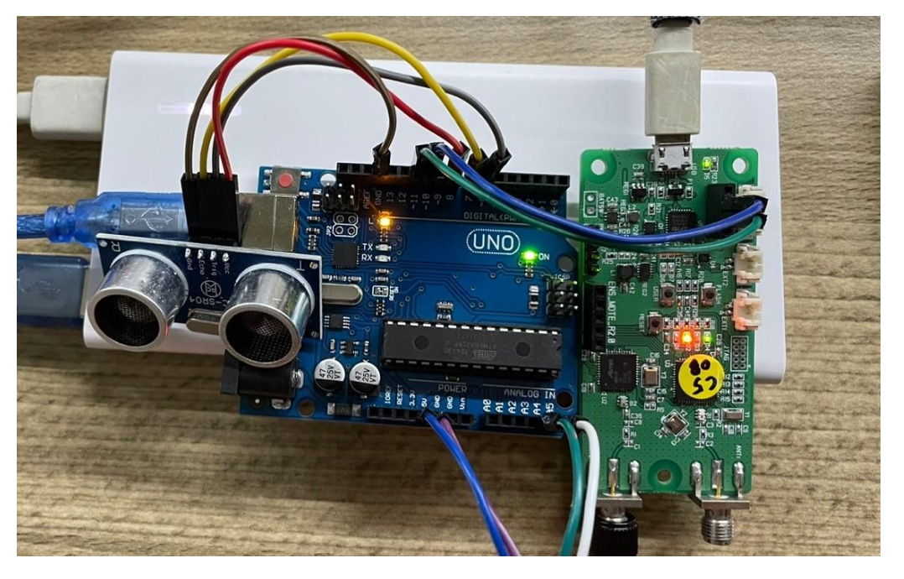
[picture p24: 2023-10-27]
docs/files/arduino and wisun module.png

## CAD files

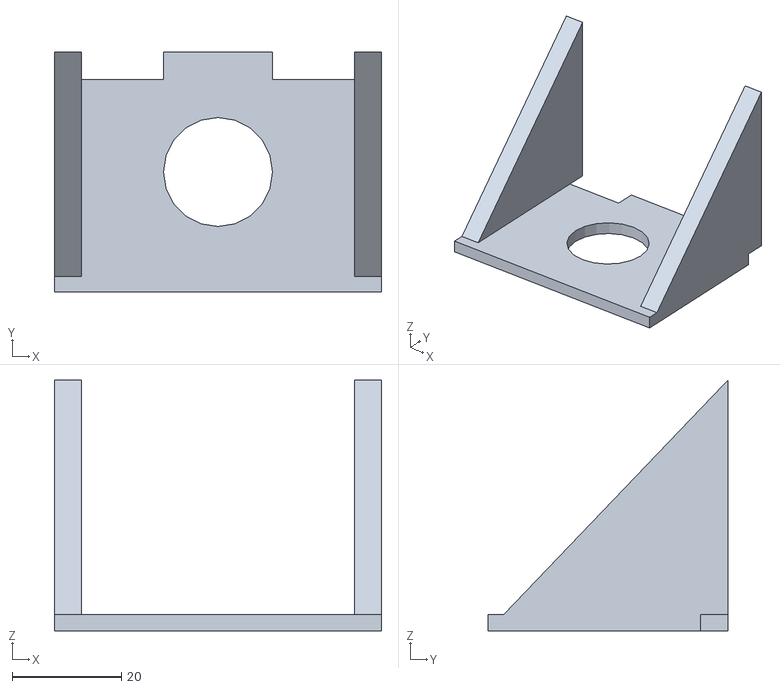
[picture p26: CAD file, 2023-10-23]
docs/files/wing_2.stl
60.0 x 44.0 x 46.0

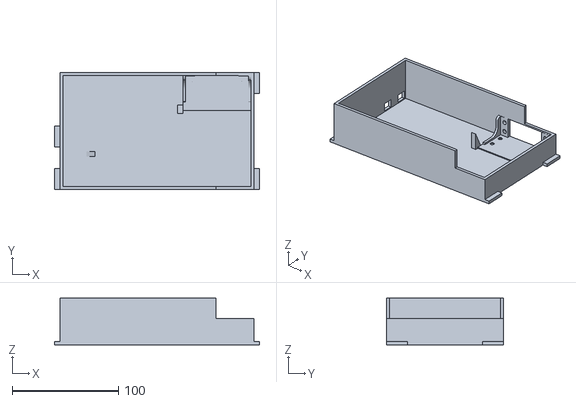
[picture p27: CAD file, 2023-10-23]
docs/files/bottom case v5.stl
193.0 x 110.3 x 44.0

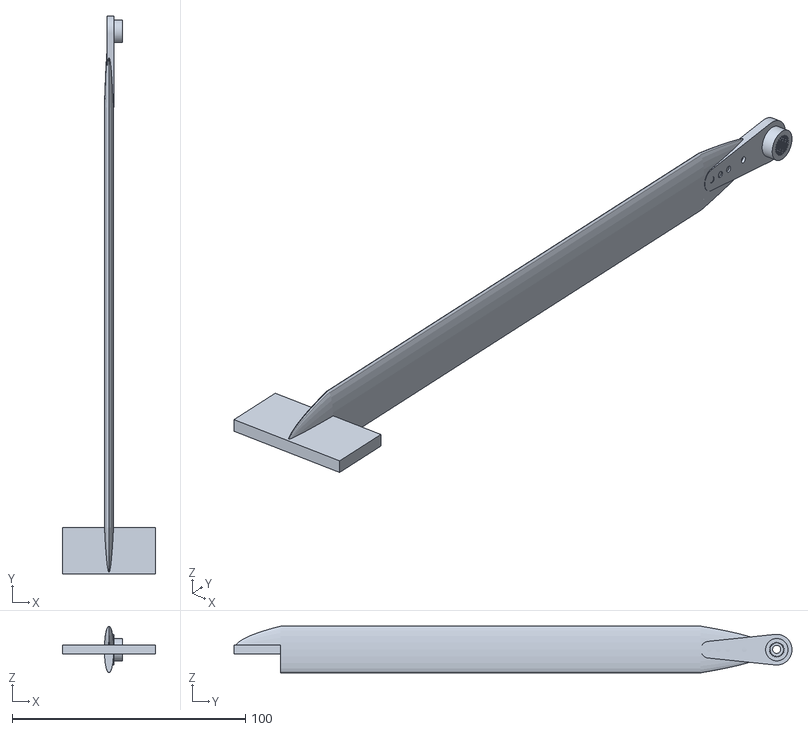
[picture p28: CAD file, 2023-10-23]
docs/files/arm.stl
40.0 x 239.1 x 20.0

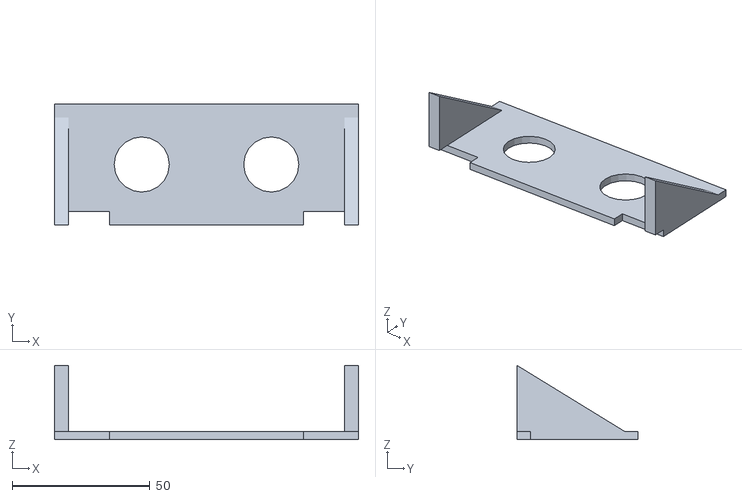
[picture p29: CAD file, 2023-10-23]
docs/files/wing_1.stl
110.3 x 44.0 x 27.0

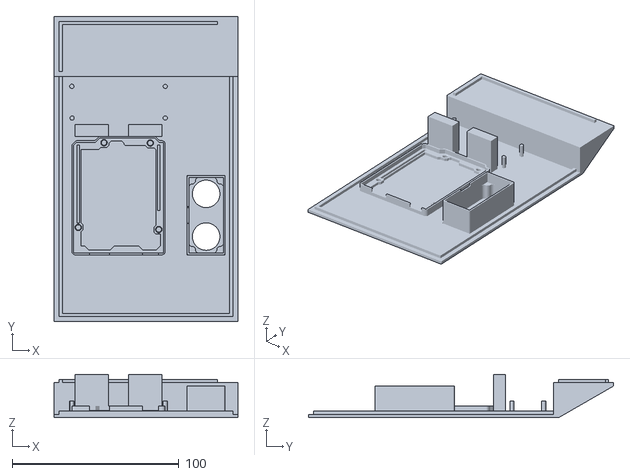
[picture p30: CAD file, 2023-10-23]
docs/files/top case v5.stl
110.3 x 183.0 x 26.0

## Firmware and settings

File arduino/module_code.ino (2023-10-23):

#include <Servo.h>
#include <SoftwareSerial.h>
#include <NewPing.h>
#include <Adafruit_PWMServoDriver.h>

// wi-sun용 시리얼 통신 포트
#define RX 10 // blue
#define TX 11 // green

#define MOTOR_DRIVER_VCC    8

// 초음파 센서
#define TRIGGER_PIN  6 // gray
#define ECHO_PIN     7 // yellow
#define MAX_DISTANCE 500

// 서보모터
Servo servo;
// 모터 드라이버-서보모터
Adafruit_PWMServoDriver pwm = Adafruit_PWMServoDriver();

// 기본 시리얼 통신 포트 데이터
char serial_data = '0';

// wi-sun용 시리얼 통신 포트 지정
SoftwareSerial mySerial(RX, TX);
// wi-sun용 시리얼 통신 포트 데이터
char myserial_rx = '0'; 

// 초음파 센서
NewPing sonar(TRIGGER_PIN, ECHO_PIN, MAX_DISTANCE);
uint8_t myserial_tx = 0;





void setup() {
  Serial.begin(9600);
  mySerial.begin(9600);

  servo.attach(9);

  pinMode(MOTOR_DRIVER_VCC, OUTPUT);

  pwm.begin();
  pwm.setPWMFreq(51);
}


void loop() {
  digitalWrite(MOTOR_DRIVER_VCC, HIGH);


  // 키보드 입력 (서보 작동 테스트용)
  if (Serial.available()) {
    // serial_data = Serial.read();
    // Serial.println("From keyboard: "); Serial.print(serial_data);

    // if (serial_data == '0') { // 올림
    //   Serial.println("motor up");
    //   servo.write(90);
    //   delay(100);
    // } else if (serial_data == '1') { // 내림
    //   Serial.println("motor down");
    //   servo.write(0);
    //   delay(100);
    // }

    // 시리얼 모니터로 값 입력
    int a = Serial.parseInt();
    // 받은 값의 범위 0~180을 펄스길이 150~600으로 매핑
    // ra의 최대 최소를 150, 600을 넘지 않게
    int ra = constrain(map(a, 0, 180, 150, 600), 150, 600);

    // pca9685 모듈의 0번 포트에 연결된 서보를 ra만큼 회전
    pwm.setPWM(0, 0, ra);

    // 시리얼 모니터에 출력
    Serial.print('('); Serial.print(a); Serial.print(','); Serial.print(ra); Serial.println(')');
    delay(10);
  }

  // Wi-SUN -> 아두이노 (서보 제어)
  if (mySerial.available()) {
    myserial_rx = mySerial.read(); // UART1으로 서보 제어 값 읽기
    Serial.println("Servo control get: "); Serial.println(myserial_rx);

    // 모터 제어
    if (myserial_rx == '0' || myserial_rx == 0) { // 주차 안됨: 차단바 올림
      // servo.write(90); // TODO: pwm으로 변경
      pwm.setPWM(0, 0, constrain(map(45, 0, 180, 150, 600), 150, 600));
      Serial.print("myserial: "); Serial.println("0");
      delay(1000);
    } else if (myserial_rx == '1' || myserial_rx == 1) { // 주차 됨: 차단바 내림
      // servo.write(0); // TODO: pwm으로 변경
      pwm.setPWM(0, 0, constrain(map(135, 0, 180, 150, 600), 150, 600));
      Serial.print("myserial: "); Serial.println("1");
      delay(1000);
    }
  }

  // 아두이노 -> Wi-SUN (초음파 값 전송)
  myserial_tx = (uint8_t)sonar.ping_cm(); // 초음파 센서 값 읽기
  if (myserial_tx > 200) {
    myserial_tx = 200;
  }
  mySerial.write(myserial_tx); // UART1으로 초음파 센서 값 쓰기
  Serial.print("Sonar value send: "); Serial.println(myserial_tx); // 시리얼 모니터에 출력
  delay(1000);
}

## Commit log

2023-10-23 writing readme
    [arm.stl, bottom case v5.stl, top case v5.stl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]
2023-10-27 주차장 모듈 부품 및 전체 구조 사진 업로드
2023-10-27 모듈 실제 모습 사진 업로드
2023-10-27 README 주차장 모듈 파트 update.md
2023-10-27 Casing Modeling 사진 파일 업로드
2023-10-27 README Casing 파트 업데이트.md
